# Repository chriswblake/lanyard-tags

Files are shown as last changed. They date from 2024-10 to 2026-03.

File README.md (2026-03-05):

# Lanyard Tags
Fun decorations to add to your lanyard during a conference or event. They are super easy to 3D print and support tapping with your phone! 🤓

| Front | Back |
| :-: | :-: |
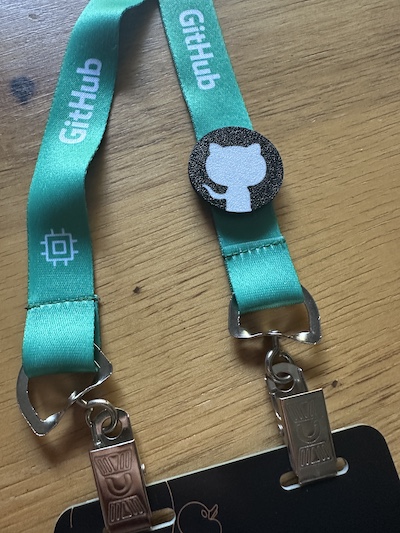
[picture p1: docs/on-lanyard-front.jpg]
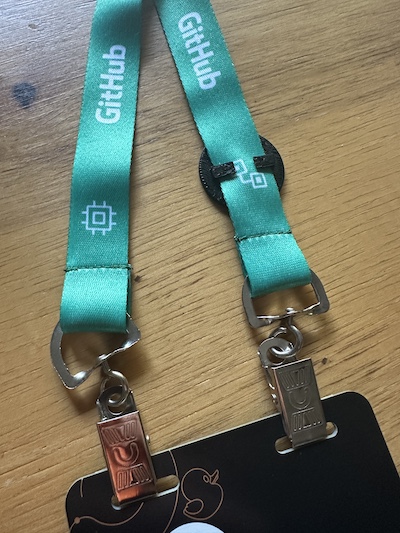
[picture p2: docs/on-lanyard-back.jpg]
|  |  |

<table>
<tr>
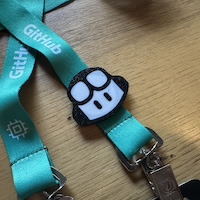
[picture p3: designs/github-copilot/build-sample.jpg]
   <td align="center"><br/>GitHub Copilot<br/></td>
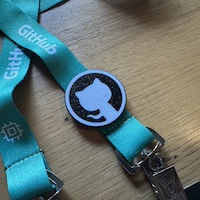
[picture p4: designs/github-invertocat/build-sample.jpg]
   <td align="center"><br/>GitHub Invertocat<br/></td>
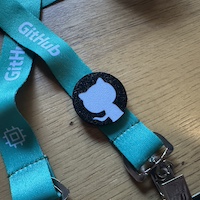
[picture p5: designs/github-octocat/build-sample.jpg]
   <td align="center">GitHub Octocat<br/>(Mona)<br/></td>
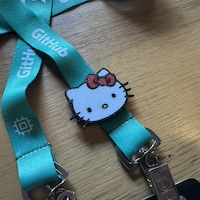
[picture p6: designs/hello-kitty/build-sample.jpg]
   <td align="center">Hello Kitty<br/>(Mona's lost twin?)<br/></td>
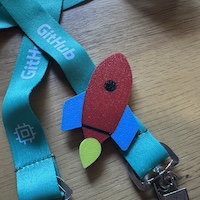
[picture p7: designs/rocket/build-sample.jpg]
   <td align="center"><br/>Rocket<br/></td>
</tr>
</table>

## How to Use
If you received your tag prebuilt, it came preloaded with a link to these instructions. Using an NFC tool app, you can overwrite the default content to make it your own.

Examples:
- Your digital business card (name, email, phone, etc.)
- A website link
    - LinkedIn profile
    - GitHub profile
    - Instagram profile
    - Personal website
- WiFi credentials

### Download the app
If your phone supports tapping to pay at a store, it will likely support reading and writing NFC tags. Below are 2 recommendations:

- NFC Tools: [iOS](https://apps.apple.com/us/app/nfc-tools/id1252962749), [Android](https://play.google.com/store/apps/details?id=com.wakdev.wdnfc)
- BLK Cards: [iOS](https://apps.apple.com/us/app/blk-cards/id6443552250), [Android](https://play.google.com/store/apps/details?id=hk.emertech.blk)

###  Update the tag
Use an app to change the tag content to a website, social profile, or virtual business card.

1. Open the **NFC Tools** app
1. Tap the `Write` button.
1. Tap the `Add a record` button.
1. Select the type of record and fill in the details.
1. Verify the number of bytes is less than 504 (the tag's capacity).
1. Tap the `Write` button and it will say "Ready to Scan".
1. Hold your phone near the tag, similar to tapping to pay at a store.
1. The app will show success and the tag is ready to be used.

### Read a tag
If you made it this far, you likely know how to read a tag. 😉 If not, here are the steps:

1. Bring your phone near the tag, similar to tapping to pay at a store.
    1. Your phone will show a notification with the tag's content.
1. Tap the notification to open the link, contact card, or other content.

## Build your own 🤓
That's cool and all, but how do I make one?!  
Check out the [build your own](docs/build-your-own.md) page for a step-by-step guide. 🧑‍🚀

## Design your own 🎨
I have an idea for a design! Can you help me make it? Please! 🥺  
Absolutely! Check out the [design your own](docs/design-your-own.md) page. It should answer any questions you have.

Alternately, feel free to [submit your design idea as an issue](https://github.com/chriswblake/lanyard-tags/issues). Maybe someone else will pick it up! 🙋 If it gets 10+ likes, I'll make it myself. 😎

## Troubleleshooting
- **When scanned, URLs are opening in a web browser instead of the app.**  
There is a not-so-obvious iOS setting for 'Universal Links' which simply remembers what you did last time.
    - To disable Universal Links, long-press the link and select **Open in Safari**. In the future, related links will open in a web browser instead of the app.
    - To enable Universal Links, long-press the link and select **Open in (app name)**. In the future, related links will open in the app instead of a web browser.

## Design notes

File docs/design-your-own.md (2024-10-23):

## Design your own 🎨
Missing a design you would like? Here is a guide to make your own!

Alternately, feel free to [submit your design idea as an issue](https://github.com/chriswblake/lanyard-tags/issues). Maybe someone else will pick it up! 🙋 If it gets 10+ likes, I'll make it myself. 😎

### Tools and Materials
The following were the tools and materials used for creating the existing designs.
Naturally, you can use other tools and materials but your process may need some adapting.

- [Autodesk Fusion](https://www.autodesk.com/products/fusion-360/personal)
- [Bambu Labs P1S 3D Printer](https://bambulab.com/en-us/p1)
    - 0.4mm nozzle
- [Bambu Labs Automatic Material System (AMS)](https://us.store.bambulab.com/products/ams-multicolor-printing)
- [Bambu Studio](https://bambulab.com/en/download/studio)
- [PLA Filament](https://store.bambulab.com/products/pla-basic-filament)
- [NFC Stickers](https://www.amazon.com/gp/product/B0CPJBP3R7)

### Design Constraints
| Design Constraint | Reason |
| --- | --- |
| NFC sticker void thickness: 0.4mm | Prevents the print nozzle dragging in the filament on higher layers. |
| Min Text Font: 4pt | The text will become unreadable. |
| Min Text Character Spacing: 15 | Letters may touch causing text to be unreadable. |
| Do not remove NFC mark | Users need a reminder that the functionality is there. | 
| Max Colors: 4 | An AMS is required. Most do not have more than 4 colors. |
| Lanyard Width: 20mm | The back hook slightly pinches the lanyard to avoid slipping. |

### Printing Constraints
| Printing Constraint | Reason |
| --- | --- |
| Body Layer Height: 0.2mm | Models are designed with changes intervals of 0.2mm. Also, this is a common printing height.  |
| Hook Layer Height: 0.08mm | Hooks are cantilevers and would normally need supports. With the angle and lower layer height, suppports aren't needed. |
| Pause at layer 5 | An NFC sticker is manually placed in the void area. |

## 1. Make a Design
1. Look at the [existing designs](designs.md) to pick one that is similar to what you want.
1. Copy the existing design folder and modify the files.
    - Keep all files related to your design in that folder.
1. Open the `.f3d` file in Fusion 360.
    - Modify the design to your liking.
    - Follow the above design constraints to avoid quailty issues.
1. In Fusion 360, export the bodies as `.stl` files.
    - Tip: If you right-click the root component, you can export all visible bodies in one file. Hidden bodies will not be exported.

## 2. Prepare for Printing then Print
1. Open the existing `3mf` file in Bambu Studio (or Prusa Slicer).
1. At the top, select the  **Prepare** tab.
1. On the left, under the **Process** section, click the **Objects** view.
1. Find the existing design and expand it to show the internal `stl` files.
    - Example: `frame.stl`, `insert-white.stl`
    - Do not delete this design. It is already modified with adaptive layer heights.
1. Right click an `.stl` file and select **Replace with STL**. Select the files for your design.
1. At the top, select the **Preview** tab.
1. Ensure the layers look correct.
    - The nfc sticker void should be 2 layers (or lack of layers).
    - The text on the back should be 1 layer. Letters should not be touching.
    - The hook should be several thinners layers (0.08mm instead of 0.2mm).
1. Print the design! :)
    - It will pause before printing layer 5. Place the NFC sticker in the round pocket and resume printing.

## 3. (optional) Share your design
If you want to share your new design, submit a pull request. :)

1. Fork this repository.
    - This will create a copy of the repository in your account so you can freely modify it.
    - This will allow you to target your PR at this repository and pull updates from the original.
1. Export your design from Fusion 360 as a `.f3d` file. Add it to your design folder.
1. Take a real picture of your design, resized to 200x200 pixels. Name it `build-sample.jpg` and add it to your design folder.
1. Add the picture and its nam to the [designs](designs.md) list.
1. Create a pull request targeting the `main` branch.
    - Tip: Add a short description and any special notes to make it easier to review.
    - I will do a test print, and if it all works, I will merge your PR! (and add it to my lanyard) 🤓

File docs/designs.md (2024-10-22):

# Designs

Below is a list of all the designs that are available in this repository.
Feel free to submit a PR to [add your own design](design-your-own.md)! 🧑‍🚀 But...please keep them coding related. 🤓

| Picture | Name `|
|-|-|
|  | GitHub Copilot |
|  | GitHub Invertocat |
|  | GitHub Octocat (Mona) |
|  | Hello Kitty (Mona's lost twin?) |
|  | Rocket |

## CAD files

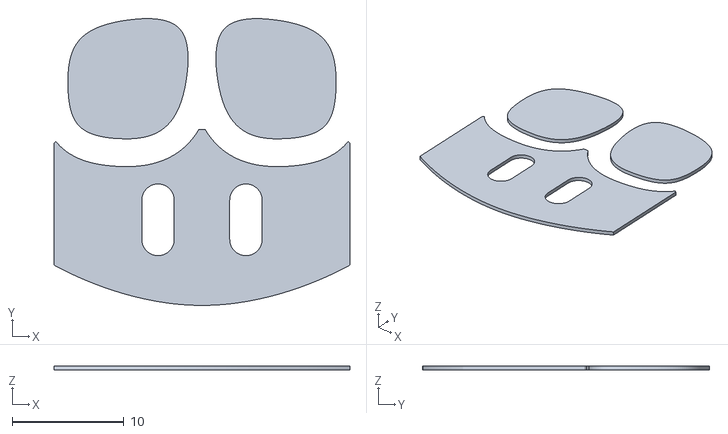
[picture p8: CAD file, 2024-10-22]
designs/github-copilot/insert-white.stl
26.4 x 25.6 x 0.4

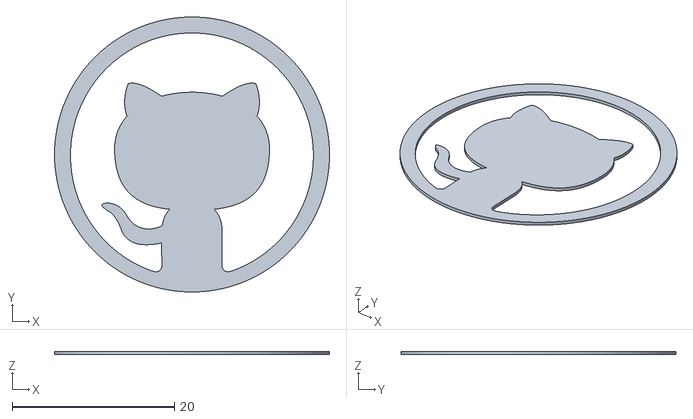
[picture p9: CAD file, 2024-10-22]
designs/github-invertocat/insert-white.stl
33.9 x 33.9 x 0.4

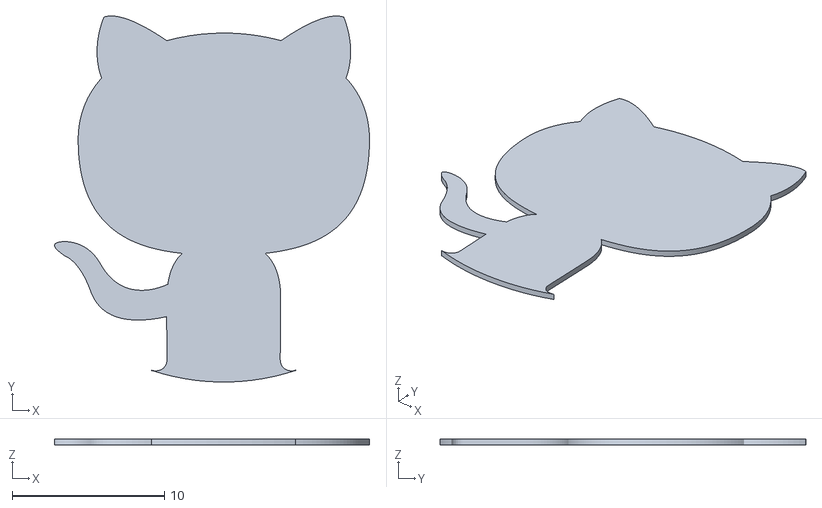
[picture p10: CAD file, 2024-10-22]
designs/github-octocat/insert-white.stl
20.7 x 24.0 x 0.4

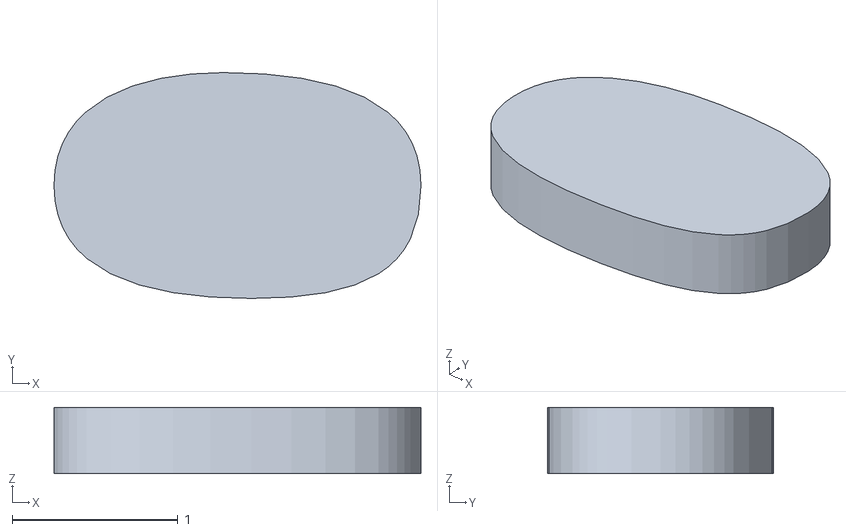
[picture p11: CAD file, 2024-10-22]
designs/hello-kitty/insert-yellow.stl
2.21 x 1.36 x 0.4

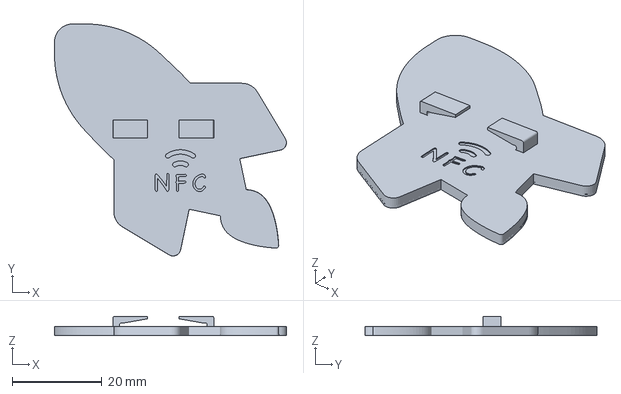
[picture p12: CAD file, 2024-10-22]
designs/rocket/rocket.3mf
51.7 x 51.7 x 4.30 mm

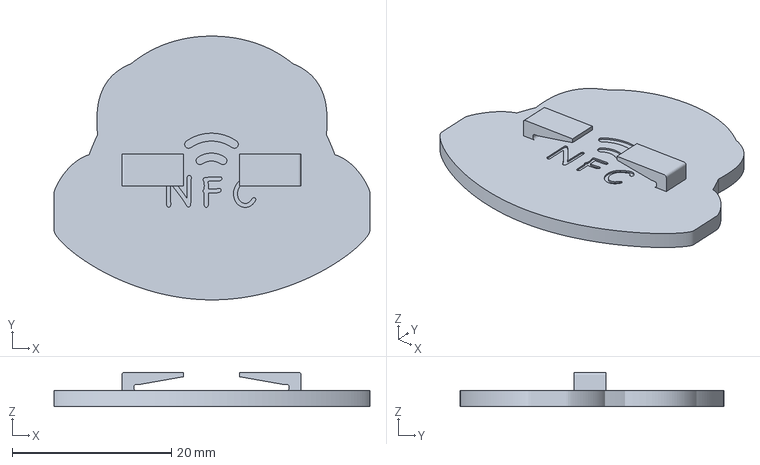
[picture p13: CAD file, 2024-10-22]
designs/github-copilot/github-copilot.3mf
39.7 x 33.1 x 4.30 mm

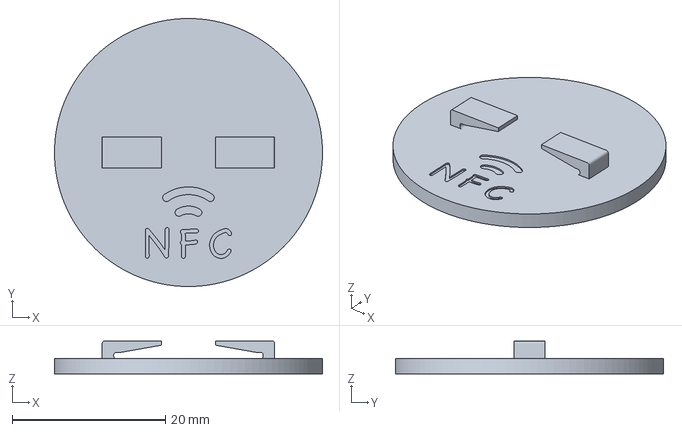
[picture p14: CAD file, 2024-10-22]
designs/github-invertocat/github-invertocat.3mf
34.9 x 34.9 x 4.30 mm

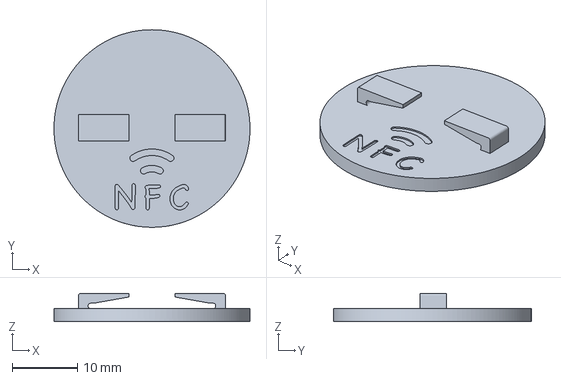
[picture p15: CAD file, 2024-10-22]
designs/github-octocat/github-octocat.3mf
30.0 x 30.2 x 4.30 mm

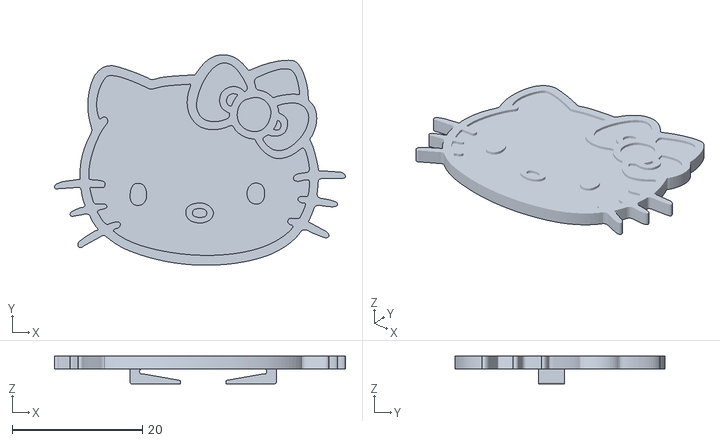
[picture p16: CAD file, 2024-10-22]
designs/hello-kitty/frame.stl
44.7 x 32.3 x 4.30

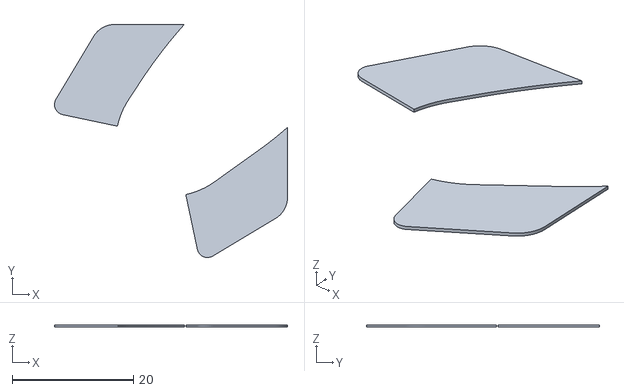
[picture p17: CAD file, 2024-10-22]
designs/rocket/insert-blue.stl
38.5 x 38.5 x 0.4

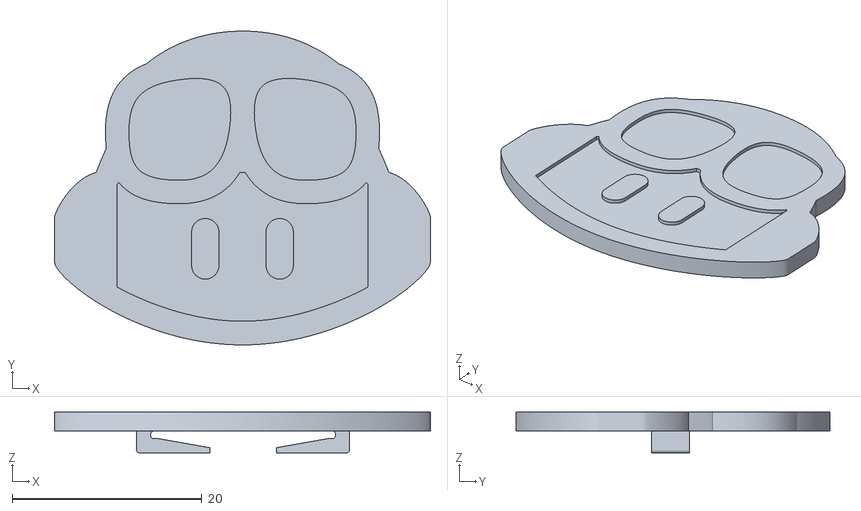
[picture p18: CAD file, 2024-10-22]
designs/github-copilot/frame.stl
39.7 x 33.1 x 4.30

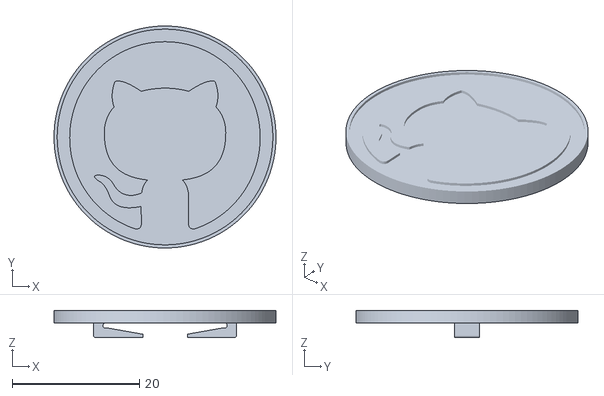
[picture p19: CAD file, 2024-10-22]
designs/github-invertocat/frame.stl
34.9 x 34.9 x 4.30

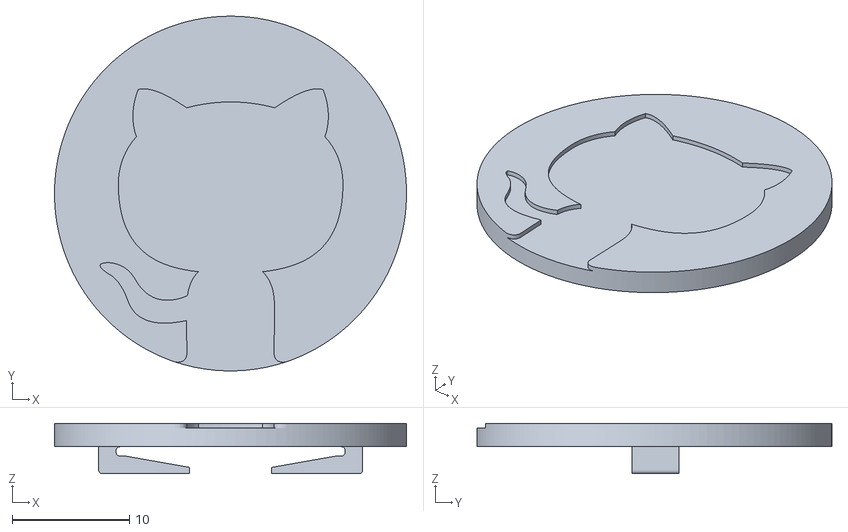
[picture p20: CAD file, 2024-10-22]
designs/github-octocat/frame.stl
30.0 x 30.2 x 4.30

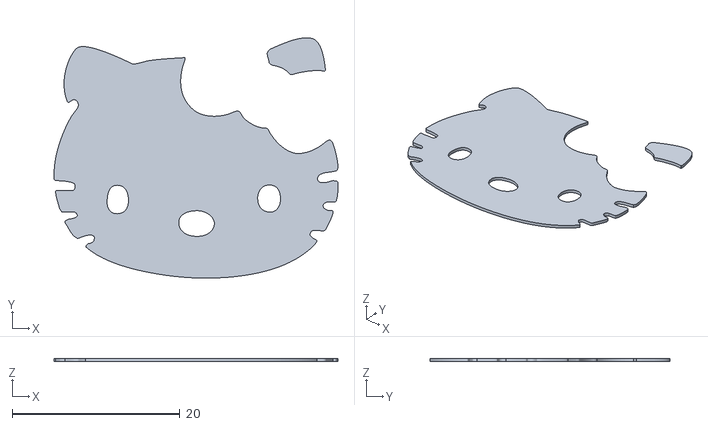
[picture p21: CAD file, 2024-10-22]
designs/hello-kitty/insert-white.stl
33.9 x 28.7 x 0.4

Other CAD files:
designs/rocket/insert-red.stl
designs/hello-kitty/hello-kitty.3mf
designs/rocket/insert-yellow.stl
designs/hello-kitty/insert-red.stl
designs/github-copilot/github-copilot.f3d
designs/github-invertocat/github-invertocat.f3d
designs/github-octocat/github-octocat.f3d
designs/hello-kitty/hello-kitty.f3d
designs/rocket/frame.stl
designs/rocket/rocket.f3d

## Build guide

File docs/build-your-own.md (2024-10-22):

# Build your own 🤓
Printing one of the designs is fairly simple. There is only 1 part! But... it is multicolor so an automatic material system (AMS) is required.

### Tools and Materials
The following tools and materials have been tested for printing the current designs.
Naturally, you can use other tools and materials but your process may need some adapting.

- [Bambu Labs P1S 3D Printer](https://bambulab.com/en-us/p1)
    - 0.4mm nozzle
- [Bambu Labs Automatic Material System (AMS)](https://us.store.bambulab.com/products/ams-multicolor-printing)
- [Bambu Studio](https://bambulab.com/en/download/studio)
- [PLA Filament](https://store.bambulab.com/products/pla-basic-filament)
- [NFC Stickers](https://www.amazon.com/gp/product/B0CPJBP3R7)

## Pick a design and print
A premade `.3mf` file is included for each design which contains the model and all critical print settings. No additional configuration is required.

1. Pick your favorite tag from the existing [designs](../designs/designs.md) page.
1. Open the related design folder and download the `.3mf` file.
1. Open the `.3mf` file in Bambu Studio (or Prusa Slicer).
    - All parameters are already set.
    - Adaptive layer height prints 0.2mm for the main body and 0.08mm for the hooks.
    - A pause point is included at layer 5 for inserting the NFC sticker.
    - No supports are required.
1. At the top, select the **Preview** tab.
1. At the top right, click the **Print plate** button.
1. Wait a moment for it to reach layer 6. It will pause.
1. Place an NFC sticker in the round pocket.
1. Resume the print and wait for it to finish!
1. Remove the tag and attach it to your lanyard! 🧑‍🚀
1. (Optional) See main [README](../README.md) for instructions to program the NFC sticker.

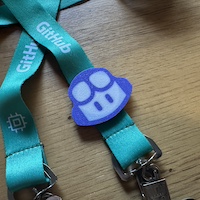
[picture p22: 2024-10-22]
designs/github-copilot/build-sample-2.jpg

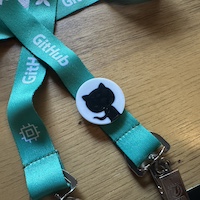
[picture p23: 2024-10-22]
designs/github-octocat/build-sample-2.jpg

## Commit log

2024-10-22 Add design: github-copilot
    [frame.stl, github-copilot.3mf, github-copilot.f3d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]
2024-10-22 Add design: github-invertocat
    [frame.stl, github-invertocat.3mf, github-invertocat.f3d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]
2024-10-22 Add design: github-octocat
    [frame.stl, github-octocat.3mf, github-octocat.f3d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]
2024-10-22 Add design: hello kitty
    [frame.stl, hello-kitty.3mf, hello-kitty.f3d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]
2024-10-22 Add design: rocket
    [frame.stl, insert-blue.stl, insert-red.stl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]
